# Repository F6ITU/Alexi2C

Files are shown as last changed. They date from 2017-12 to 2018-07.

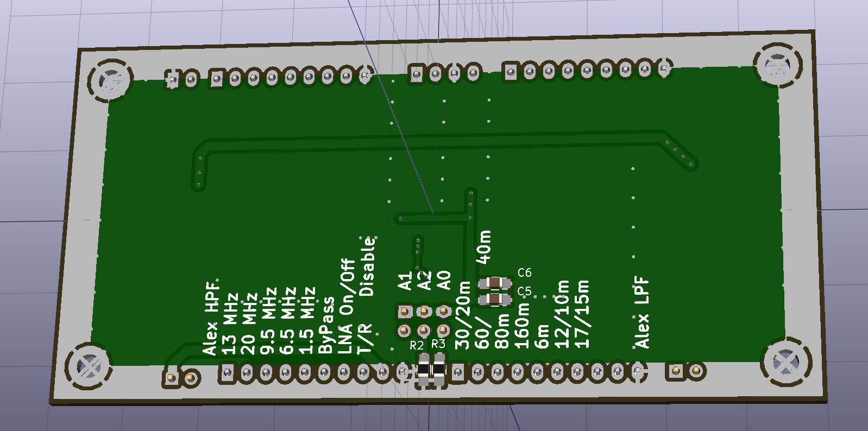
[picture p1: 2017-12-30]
Alexi2C dwn.jpg

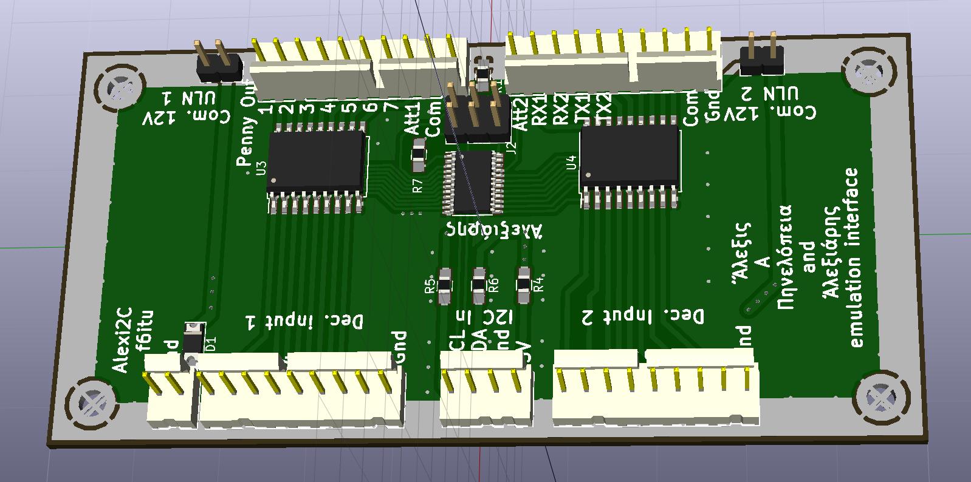
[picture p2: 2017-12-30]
Alexi2C up.jpg

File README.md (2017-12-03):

# Alexi2C

Kicad files

I2C control board interfacing 
Alexiares/Penelope input/output filter set 
with Hermes Lite 2.x & Red Pitaya 

It could also be used with a decimal/7 bits binary input for 
Hermes lite 1.0 

http://www.hermeslite.com/

This board is a fork of the DC2PD interface for the Red Pitaya
http://rz1zr.ru/files/Hermes_and_Alex_outputs.pdf

It has
been designed to 

- Control a set of Alexiares LPF and HPF filters
using the Hermes lite or Red Pitaya's I2C output (Steve KF7O or Pavel Denim's firmware).
http://pavel-demin.github.io/red-pitaya-notes/sdr-transceiver-hpsdr/

- Control a simple BCD or decimal filter (J6 output of an Hermes Lite)
In this case, the TCA9555 and the 5 pins "I2C Input" connector are not used

 === Hardware modifications===

A set of darlington (ULN2803) is used to fit the voltage 
and current requirement of both lpf and hpf boards. 

A pair of jumpers located close to the output connectors 
allow to use the "local" 12V  power rail if set, 
or any external voltage when opened. 

For hams using this board with the KF7O's Hermes Lite V1 (deprecated dev.), two connectors 
have been added to directly control the drivers in decimal mode,
thus to control a Penelope, Alexiares or an Alex SV1AL softrock based 
"Big Mobo" filter set ( or any filter 
board using negative logic band switching) 

Please note that the antenna and attenuator commands need a separate 
board if an Alex lpf/hpf filter set is already used (Pavel's firmware). 

An antenna switching board project could be downloaded and/or forked from 

https://github.com/F6ITU/Alexiares_Coax_Out

(attenuators are integrated on the HPF filter board, under design)

When using AlexI2C, Alexandrie control board, the original I2S interface

https://github.com/F6ITU/Alexandrie

should NOT be used (it seems obvious, but who knows...)

AlexI2C acts as an "almost complete" substitute of the original board and is 
dedicated to people who don't want to use Alexiares's I2S protocol.

3D image of the board are stored on this repo

Alexi2C dwn.jpg

Alexi2C up.jpg

Board's dimensions are oversized to fit the 5x10 and 10x10cm 
size of all board of the Hermes project under Kicad: 

AlexI2C

Alexandrie 

Alexiares_Coax_Out

Alexiares_HPF

Alexiares_LPF

Mentor

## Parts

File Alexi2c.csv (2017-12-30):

Component Count: | 26
Ref | Value | Footprint | Datasheet | Manufacturer | Vendor
C5 | 100n | Capacitors_SMD:C_0805_HandSoldering
C6 | 10n | Capacitors_SMD:C_0805_HandSoldering
D1 | D | Diodes_SMD:D_2010
J1 | Conn_01x04 | conn_kk100:kk100_22-23-2041
J2 | Conn_02x03_Odd_Even | Pin_Headers:Pin_Header_Straight_2x03_Pitch2.54mm
J3 | Conn_01x02 | conn_kk100:kk100_22-23-2021
J4 | Conn_01x10 | conn_kk100:kk100_22-23-2101
J5 | Conn_01x10 | conn_kk100:kk100_22-23-2101
J6 | Conn_01x09 | conn_kk100:kk100_22-23-2091
J11 | Conn_01x09 | conn_kk100:kk100_22-23-2091
J12 | Conn_01x02 | Pin_Headers:Pin_Header_Straight_1x02_Pitch2.54mm
J13 | Conn_01x02 | Pin_Headers:Pin_Header_Straight_1x02_Pitch2.54mm
R1 | 4k7 | Resistors_SMD:R_0805_HandSoldering
R2 | 4k7 | Resistors_SMD:R_0805_HandSoldering
R3 | 4k7 | Resistors_SMD:R_0805_HandSoldering
R4 | 0R | Resistors_SMD:R_0805_HandSoldering
R5 | 4k7 | Resistors_SMD:R_0805_HandSoldering
R6 | 4k7 | Resistors_SMD:R_0805_HandSoldering
R7 | 4k7 | Resistors_SMD:R_0805_HandSoldering
U2 | TCA9555PWR | Housings_SSOP:TSSOP-24_4.4x7.8mm_Pitch0.65mm
U3 | ULN2803A | Housings_SOIC:SOIC-18W_7.5x11.6mm_Pitch1.27mm
U4 | ULN2803A | Housings_SOIC:SOIC-18W_7.5x11.6mm_Pitch1.27mm

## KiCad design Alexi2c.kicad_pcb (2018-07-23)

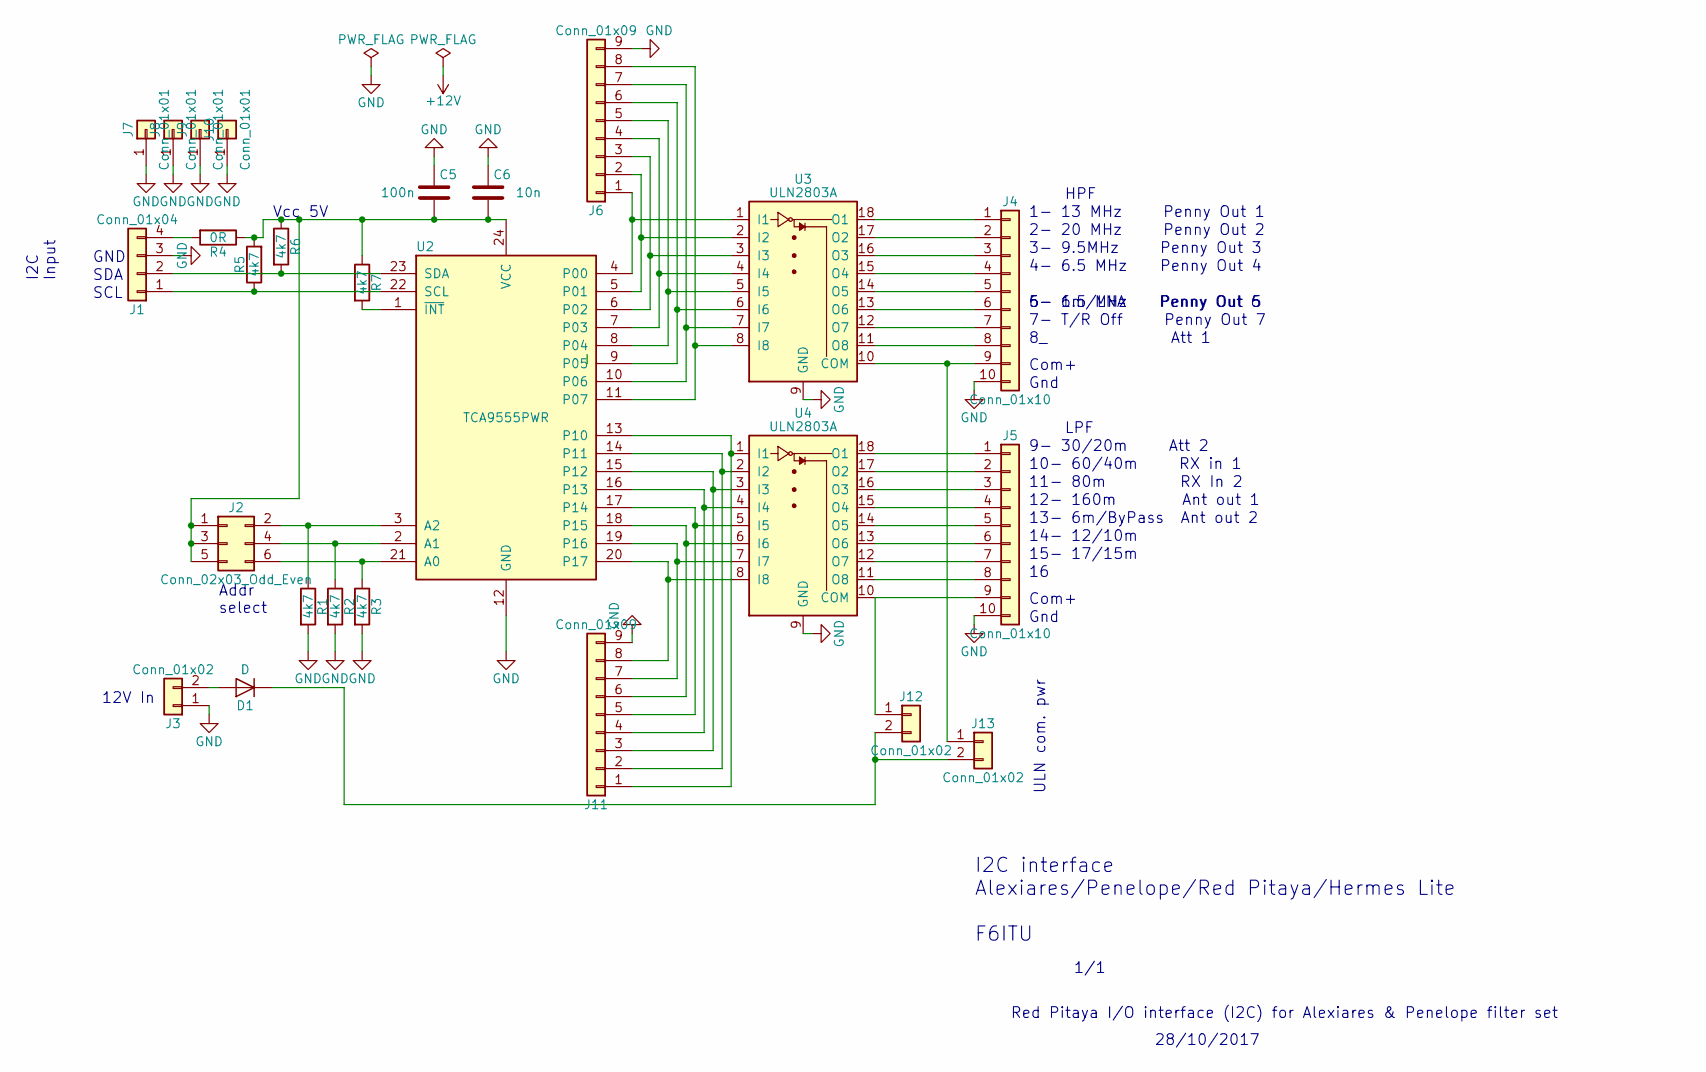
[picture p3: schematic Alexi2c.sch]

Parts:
C5: 100n; C_0805_HandSoldering
C6: 10n; C_0805_HandSoldering
D1: D; D_2010
J1: Conn_01x04; kk100_22-23-2041
J2: Conn_02x03_Odd_Even; Pin_Header_Straight_2x03_Pitch2.54mm
J3: Conn_01x02; kk100_22-23-2021
J4, J5: Conn_01x10; kk100_22-23-2101
J6, J11: Conn_01x09; kk100_22-23-2091
J7, J8, J9, J10: Conn_01x01; MountingHole_3.2mm_M3_ISO14580_Pad
J12, J13: Conn_01x02; Pin_Header_Straight_1x02_Pitch2.54mm
R1, R2, R3, R5, R6, R7: 4k7; R_0805_HandSoldering
R4: 0R; R_0805_HandSoldering
U2: TCA9555PWR; TSSOP-24_4.4x7.8mm_Pitch0.65mm
U3, U4: ULN2803A; SOIC-18W_7.5x11.6mm_Pitch1.27mm

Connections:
GND: C5.1, C6.1, J1.3, J3.1, J4.10, J5.10, J6.9, J7.1, J8.1, J9.1, J10.1, J11.9, R1.2, R2.2, R3.2, U2.12 (GND), U3.9 (GND), U4.9 (GND)
unnamed: C5.2, C6.2, J2.1, J2.3, J2.5, R4.1, R5.2, R6.1, R7.1, U2.24 (VCC)
unnamed: D1.1 (K), J12.2, J13.2
unnamed: D1.2 (A), J3.2
unnamed: J1.1, R5.1, U2.22 (SCL)
unnamed: J1.2, R6.2, U2.23 (SDA)
unnamed: J1.4, R4.2
unnamed: J2.2, R1.1, U2.3 (A2)
unnamed: J2.4, R2.1, U2.2 (A1)
unnamed: J2.6, R3.1, U2.21 (A0)
unnamed: J4.1, U3.18 (O1)
unnamed: J4.2, U3.17 (O2)
unnamed: J4.3, U3.16 (O3)
unnamed: J4.4, U3.15 (O4)
unnamed: J4.5, U3.14 (O5)
unnamed: J4.6, U3.13 (O6)
unnamed: J4.7, U3.12 (O7)
unnamed: J4.8, U3.11 (O8)
unnamed: J5.1, U4.18 (O1)
unnamed: J5.2, U4.17 (O2)
unnamed: J5.3, U4.16 (O3)
unnamed: J5.4, U4.15 (O4)
unnamed: J5.5, U4.14 (O5)
unnamed: J5.6, U4.13 (O6)
unnamed: J5.7, U4.12 (O7)
unnamed: J5.8, U4.11 (O8)
unnamed: J6.1, U2.4 (P00), U3.1 (I1)
unnamed: J6.2, U2.5 (P01), U3.2 (I2)
unnamed: J6.3, U2.6 (P02), U3.3 (I3)
unnamed: J6.4, U2.7 (P03), U3.4 (I4)
unnamed: J6.5, U2.8 (P04), U3.5 (I5)
unnamed: J6.6, U2.9 (P05), U3.6 (I6)
unnamed: J6.7, U2.10 (P06), U3.7 (I7)
unnamed: J6.8, U2.11 (P07), U3.8 (I8)
unnamed: J11.1, U2.13 (P10), U4.1 (I1)
unnamed: J11.2, U2.14 (P11), U4.2 (I2)
unnamed: J11.3, U2.15 (P12), U4.3 (I3)
unnamed: J11.4, U2.16 (P13), U4.4 (I4)
unnamed: J11.5, U2.17 (P14), U4.5 (I5)
unnamed: J11.6, U2.18 (P15), U4.6 (I6)
unnamed: J11.7, U2.19 (P16), U4.7 (I7)
unnamed: J11.8, U2.20 (P17), U4.8 (I8)
unnamed: J5.9, J12.1, U4.10 (COM)
unnamed: J4.9, J13.1, U3.10 (COM)
unnamed: R7.2, U2.1 (~INT)

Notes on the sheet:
12V In
Addr select
I2C Input
I2C interface Alexiares/Penelope/Red Pitaya/Hermes Lite F6ITU
SDA
SCL
GND
Vcc 5V
1- 13 MHz Penny Out 1
2- 20 MHz Penny Out 2
3- 9.5MHz Penny Out 3
4- 6.5 MHz Penny Out 4
5- 1.5 MHz Penny Out 5
6- 6m/LNA Penny Out 6
7- T/R Off Penny Out 7
8_ Att 1
9- 30/20m Att 2
10- 60/40m RX in 1
11- 80m RX In 2
12- 160m Ant out 1
13- 6m/ByPass Ant out 2
14- 12/10m
15- 17/15m
Com+
Gnd
HPF
LPF
1/1
28/10/2017
Red Pitaya I/O interface (I2C) for Alexiares & Penelope filter set
ULN com. pwr

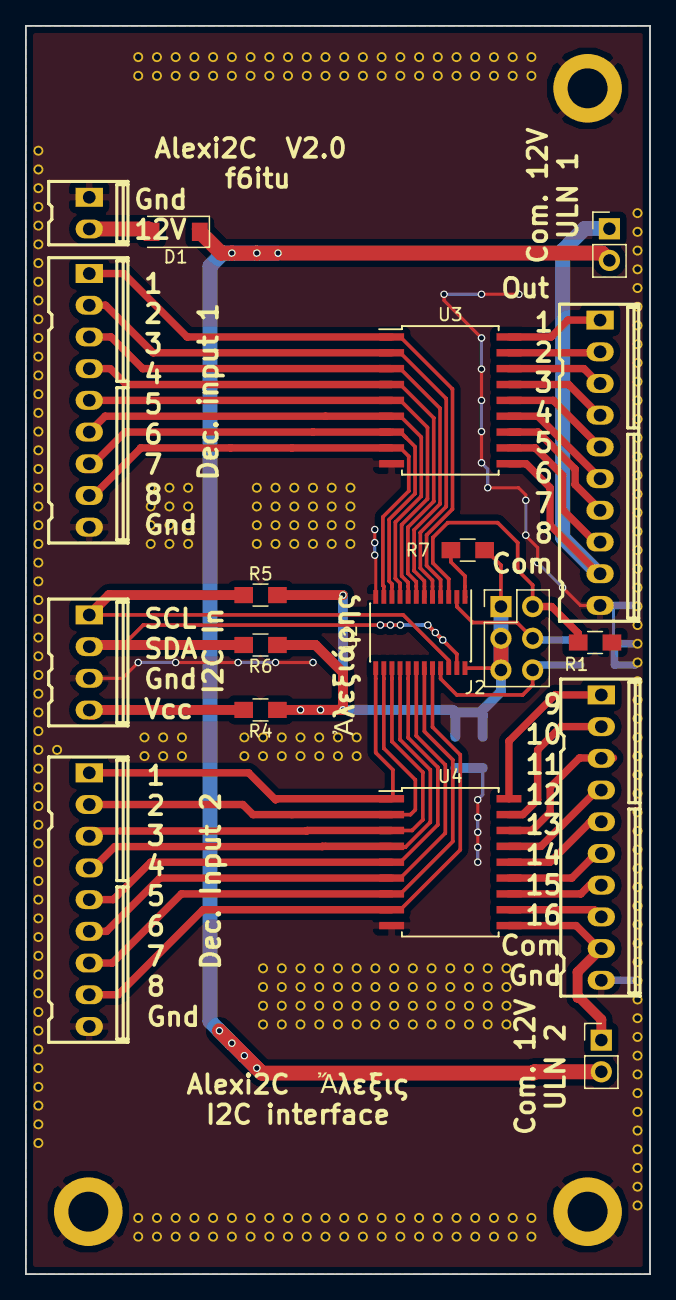
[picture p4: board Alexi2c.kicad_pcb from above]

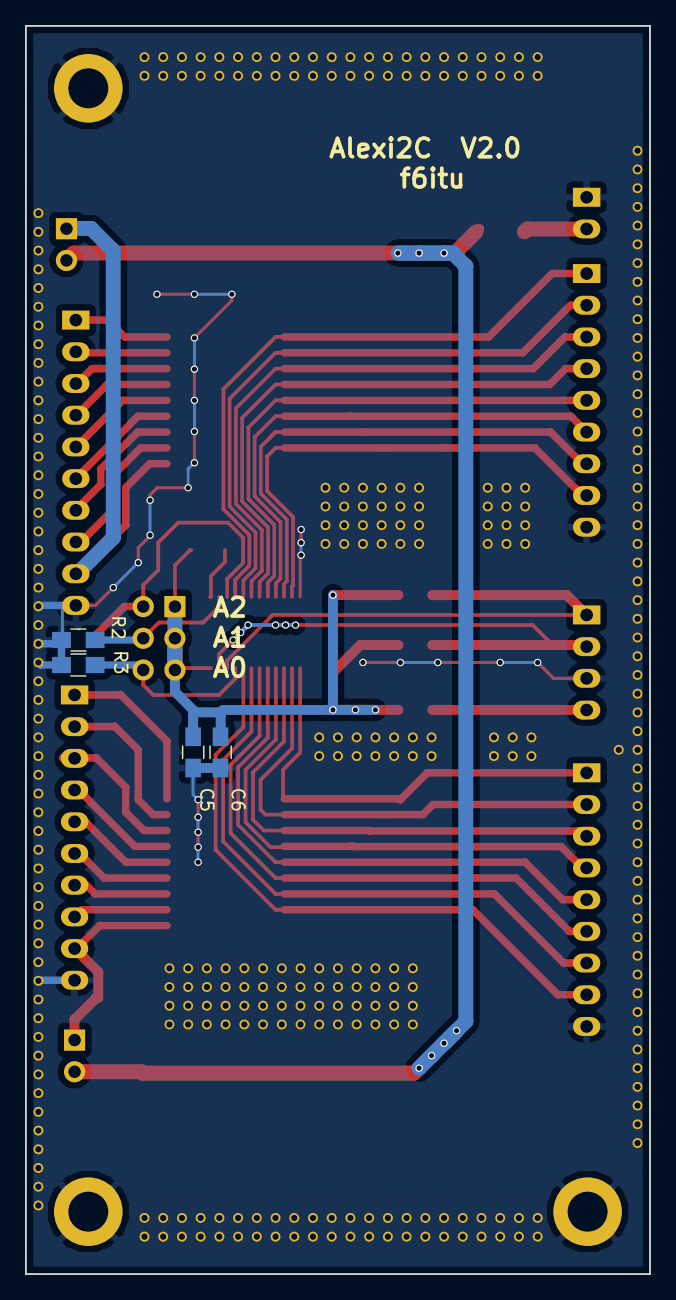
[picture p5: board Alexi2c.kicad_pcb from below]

Board: 2 copper layers, 50.0 x 100.0 mm, 25 parts (4 on the bottom side), 45 nets.

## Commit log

2017-11-01 RTM 1
    [Alexi2c.kicad_pcb, Alexi2c.sch]
2017-11-02 Readme cleanup
    [Alexi2c.kicad_pcb, Alexi2c.sch]
2017-11-27 new I2C decoder module
    [Alexi2c.kicad_pcb, Alexi2c.sch]
2017-12-22 added protec. diode, I2C Pull-up, I2C Vdd strap
    [Alexi2c.kicad_pcb, Alexi2c.sch]
2017-12-30 image and BOM added, minor changes
    [Alexi2c.csv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]
2017-12-30 Gerber files added
    [Alexi2c-B.Cu.gbr, Alexi2c-B.Mask.gbr, Alexi2c-B.SilkS.gbr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]
2018-07-05 new stitching, minor silkmask mods
    [Alexi2c.kicad_pcb]
2018-07-23 Alexi2C V2.0 RTM
    [Alexi2c.kicad_pcb]
